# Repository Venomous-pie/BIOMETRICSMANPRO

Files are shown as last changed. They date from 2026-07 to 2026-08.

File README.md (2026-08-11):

# Biometrics Time-In/Out System

An ESP32-based biometric attendance system. A fingerprint scanner node (WROOM) communicates wirelessly via ESP-NOW to a touchscreen display node (CrowPanel), which connects to the backend over WiFi.

---

## Table of Contents

1. [Architecture Overview](#1-architecture-overview)
2. [Hardware](#2-hardware)
3. [Power Requirements](#3-power-requirements)
4. [Wiring & Pinout](#4-wiring--pinout)
5. [Arduino IDE Setup](#5-arduino-ide-setup)
6. [Configuration Reference](#6-configuration-reference)
7. [First-Time Flash Order](#7-first-time-flash-order)
8. [Mock Server Usage](#8-mock-server-usage)
9. [Repository Layout](#9-repository-layout)
10. [Employee Sync Pipeline](#10-employee-sync-pipeline)
11. [ESP-NOW Message Types](#11-esp-now-message-types)
12. [Persistent Storage Map](#12-persistent-storage-map)
13. [Subsystem Deep-Dives](#13-subsystem-deep-dives)
14. [Development Workflow](#14-development-workflow)
15. [WROOM Serial Commands](#15-wroom-serial-commands)
16. [Testing Checklist](#16-testing-checklist)
17. [Backend API Endpoints](#17-backend-api-endpoints)
18. [Open Work & Known Issues](#18-open-work--known-issues)
19. [OTA Firmware Update Roadmap](#19-ota-firmware-update-roadmap)
20. [Design Notes](#20-design-notes)

---

## 1. Architecture Overview

Understanding the data flow before touching code will save you hours. The system has three tiers:

```
+-----------------------------------+        +-----------------------------------+
|      WROOM Node (ESP32-D0WD-V3)   |        |   CrowPanel Node (ESP32-S3 QFN56) |
|                                   |        |                                   |
|  AS608 Fingerprint Sensor         |        |  5" 800x480 Touchscreen (LVGL)    |
|  WiFi (NTP timekeeping — RTC TBD) |        |  Employee list and logs UI        |
|  WiFi (for NTP + backend calls)   |        |  WiFi (for backend sync)          |
|                                   |        |                                   |
|  Polls finger -> match -> sends   |<------>|  Receives match/enroll events     |
|  attendance event over ESP-NOW    | ESP-NOW|  Shows result screen              |
|                                   |        |                                   |
|  Handles: activation, NTP sync,   |        |  Handles: employee list sync,     |
|  fingerprint enroll/delete,       |        |  attendance log display,          |
|  factory reset                    |        |  WiFi setup UI, settings          |
+------------------+----------------+        +------------------+----------------+
                   | HTTPS (REST API)                            | HTTPS (REST API)
                   +---------------------------+-----------------+
                                               |
                                    +----------v-----------+
                                    |    ManPro Backend API |
                                    |  (demo.manpromanage- |
                                    |   ment.com or local  |
                                    |   mock server)        |
                                    +----------------------+
```

**How a time-in works, end to end:**

1. Employee places finger on the AS608 sensor on the WROOM.
2. WROOM matches the fingerprint to a stored template and resolves the employee ID.
3. WROOM sends a `{type: MATCH, emp_id: ..., ts: ...}` JSON packet to the CrowPanel via ESP-NOW.
4. CrowPanel displays the result screen (welcome / access denied) and logs the attendance locally.
5. CrowPanel uploads the log entry to the backend API over WiFi on the next sync cycle.

**ESP-NOW channel management:** Both nodes must use the same WiFi channel. The WROOM monitors the channel continuously; if the AP hops channels, the WROOM sends a `CHANNEL_HOP` notification so the CrowPanel resyncs without a reboot.

---

## 2. Hardware

| Node | Board | Chip | Role |
| --- | --- | --- | --- |
| CrowPanel | Elecrow CrowPanel 5" 800×480 | **ESP32-S3 (QFN56)** | Touchscreen UI, WiFi, backend comms |
| WROOM | ESP32-WROOM-32 dev module | **ESP32-D0WD-V3** | Fingerprint scanner, ESP-NOW bridge |

### CrowPanel SD Card Requirement (Deep Storage)

The system uses a **Smart Cache** architecture. The WROOM's AS608 fingerprint sensor acts as a fast L1 cache holding 127 active templates. The CrowPanel's SD Card acts as the primary "Deep Storage", holding an unlimited number of fingerprint templates for offline scale.

- **Requirement:** A MicroSD card (FAT32 formatted) must be inserted into the CrowPanel.
- **Directory Structure:** The firmware expects the directory `/templates/` at the root of the SD card.
- **File Format:** Templates are stored as raw 512-byte binary files (e.g., `/templates/<emp_id>_<finger_index>.bin`).

---

## 3. Power Requirements

### Supply Voltages

| Component | Voltage | Typical Current | Peak Current |
| --- | --- | --- | --- |
| ESP32-D0WD-V3 (WROOM-32 module)  | 3.3 V | ~80 mA idle | ~350 mA WiFi TX burst |
| CrowPanel ESP32-S3 (QFN56) board | 5 V (USB-C) or 3.3 V regulated | ~150 mA idle | ~500 mA with LCD backlight + WiFi |
| AS608 Fingerprint Sensor | 3.3 V | ~120 mA scanning | ~140 mA |
| DFPlayer Mini + Speaker | 5.0 V | ~20 mA idle | ~200 mA playing |

### Power Strategy

**During development:**

- Power the **CrowPanel** via its USB-C port from a PC or USB charger. The board has an onboard 3.3 V LDO — you do not need a separate regulator.
- Power the **WROOM dev board** via its USB-micro/USB-C port. Most WROOM dev boards also have a 3.3 V LDO.
- The **AS608** can be powered from the WROOM board's 3.3 V pin (labelled `3V3`). Its draw (~120–140 mA) is well within the AMS1117 LDO's 800 mA rating.

**In the final enclosure:**

- The WROOM + AS608 sub-assembly should be powered from a regulated **5 V 1 A** supply (e.g. USB wall adapter) feeding the WROOM dev board's USB connector, or via VIN if using a bare module with an external 3.3 V regulator.
- The CrowPanel should be powered independently via its USB-C connector from a **5 V 2 A** source. Its LCD backlight alone draws ~200 mA.
- **Do not share a USB port between the two boards** during development — each board needs its own Serial port for log monitoring and flashing.

### Wire Gauge

- For power rails: 26 AWG stranded is sufficient for the current levels involved.
- For UART signal lines: 28 AWG or 30 AWG.
- Keep wire runs under 30 cm to avoid voltage drop on the 3.3 V rail.

---

## 4. Wiring & Pinout

### WROOM — Complete Pin Map

| Pin | GPIO | Function | Notes |
| --- | --- | --- | --- |
| 3V3 | — | 3.3 V output | Powers AS608 |
| GND | — | Ground | Common ground for all peripherals |
| **UART1 RX** | **GPIO27** | AS608 TX -> | Connect to AS608 TXD pin |
| **UART1 TX** | **GPIO26** | AS608 RX <- | Connect to AS608 RXD pin |
| **GPIO34** | Input-only | AS608 T-OUT (touch detect) | Pulled HIGH by sensor when finger present |
| **GPIO21** | SDA | Reserved — RTC (future) | Not connected; reserved for DS3231 I2C |
| **GPIO22** | SCL | Reserved — RTC (future) | Not connected; reserved for DS3231 I2C |
| **UART2 RX** | **GPIO17** | DFPlayer TX <- | Audio RX (Use Logic Level Shifter!) |
| **UART2 TX** | **GPIO16** | DFPlayer RX -> | Audio TX (Use Logic Level Shifter!) |
| **GPIO13** | Output | Reserved — Buzzer (future) | Not connected; reserved for buzzer signal |
| **GPIO14** | Factory Reset | Active HIGH button | Uses internal pull-down; hold 5 s to wipe |

**Pins to avoid on ESP32-D0WD-V3 (WROOM-32):**

| GPIO | Reason |
| --- | --- |
| GPIO0 | Strapping pin — LOW at boot = download mode; do not pull low with external hardware |
| GPIO2 | Strapping pin — must be LOW during flash; avoid driving it during boot |
| GPIO12 | Strapping pin — sets flash voltage; keep floating or LOW |
| GPIO15 | Strapping pin — controls boot logging; keep floating for normal use |
| GPIO34–39 | Input-only — no internal pull-up/pull-down; cannot be driven as outputs |
| GPIO6–11  | Connected to internal SPI flash — do not use |

**Connector type:** JST-PH 2.0 mm 2-pin or standard 2.54 mm DuPont headers are both fine for a prototype enclosure.

---

### AS608 Fingerprint Sensor Wiring

| AS608 Pin | Connects to |
| --- | --- |
| VCC | WROOM 3V3 |
| GND | WROOM GND |
| TXD | WROOM GPIO27 (UART1 RX) |
| RXD | WROOM GPIO26 (UART1 TX) |
| T-OUT | WROOM GPIO34 |
| WAKEUP | Leave floating or tie to GND |

> The AS608 communicates at 57600 baud by default. The firmware initialises UART1 at this speed. Do not change it unless you also update `fingerprint_manager.cpp`.

---

### Audio (DFPlayer Mini) Wiring

> **Hardware Setup Notes:**
>
> - **Logic Level Converter:** The ESP32 is a 3.3V device, but the DFPlayer Mini runs best at 5V. The RX/TX lines are routed through a logic level converter to protect the ESP32 pins.
> - **Active Buzzer (Not Implemented — Future Work):** The active buzzer has not been integrated into the hardware. GPIO13 is physically reserved for it. When implemented, it requires an NPN transistor and a flyback diode to drive safely from the ESP32.

| Audio Pin | Connects to | Notes |
| --- | --- | --- |
| DFPlayer VCC | 5V Power Rail | Provide 5V for loud/clean audio |
| DFPlayer GND | Common GND | |
| DFPlayer RX | Logic Level Converter (HV) -> (LV) -> WROOM GPIO16 (TX) | Converts 3.3V TX to 5V |
| DFPlayer TX | Logic Level Converter (HV) -> (LV) -> WROOM GPIO17 (RX) | Converts 5V TX to 3.3V |
| DFPlayer SPK+ | Speaker Positive (+) | |
| DFPlayer SPK- | Speaker Negative (-) | |

_Place your audio files (e.g., `0001.mp3`, `0002.mp3`) inside a folder literally named `mp3` on the root of the SD card before inserting it into the DFPlayer._

---

### DS3231 RTC Module (Not Implemented — Future Work)

> **The DS3231 hardware RTC has not been integrated into the firmware.** GPIO21 (SDA) and GPIO22 (SCL) are physically reserved for it, and the `time_manager.cpp` file exists as a stub, but the RTC driver is not initialised at boot. The WROOM currently uses NTP as its sole time source and falls back to `millis()`-based offset if WiFi is unavailable.
>
> Integrating the DS3231 is tracked as a future implementation item. When implemented, refer to the wiring table below:

| DS3231 Pin | Planned Connection |
| --- | --- |
| VCC | WROOM 3V3 |
| GND | WROOM GND |
| SDA | WROOM GPIO21 |
| SCL | WROOM GPIO22 |
| SQW | Not connected |
| 32K | Not connected |

---

### CrowPanel — Key Pins

The CrowPanel 5" board is a self-contained unit. You do not need to wire any peripherals to it — the display, touch controller, and SD card are all onboard. The only external connection is USB-C for power and flashing.

| Function | Notes |
| --- | --- |
| USB-C | Power + Serial (CDC) for flashing and Serial Monitor |
| ESP-NOW radio | Uses onboard antenna; no external connection needed  |
| WiFi | Uses onboard antenna |

**Pins to avoid on ESP32-S3 (QFN56) (if you ever need to expand):**

| GPIO | Reason |
| --- | --- |
| GPIO0 | Strapping pin — boot mode selection |
| GPIO3 | Strapping pin |
| GPIO19, GPIO20 | USB D+/D− — used by CDC USB port |
| GPIO26–32 | Connected to OPI PSRAM — do not use |
| GPIO33–37 | Connected to onboard flash — do not use |

---

## 5. Arduino IDE Setup

**Version:** Arduino IDE 2.3.10

> Since the IDE's Tools menu settings are **per-board-selection** and do not persist per-sketch, always double-check the **Board** dropdown before flashing. Flashing the wrong sketch to the wrong board (or with the wrong partition scheme) will produce a silent bad build.

### Step 1 — Install Arduino IDE

Download the installer from https://www.arduino.cc/en/software — choose **Arduino IDE 2.3.10** (Windows Installer). Run with default options.

### Step 2 — Add the ESP32 Board Package

1. Open Arduino IDE -> **File -> Preferences**.
2. In **Additional boards manager URLs**, paste:
   ```
   https://raw.githubusercontent.com/espressif/arduino-esp32/gh-pages/package_esp32_index.json
   ```
3. Click **OK**.
4. Go to **Tools -> Board -> Boards Manager**, search for `esp32`, and install **esp32 by Espressif Systems**.
   - **Required version: 3.2.0** (or the latest 3.x release). Version 2.x is not compatible with the ESP32-S3 PSRAM driver used by the CrowPanel.

### Step 3 — Install Libraries

Open **Tools -> Manage Libraries** and install each of the following by searching the Library Manager:

**For CrowPanel:**

| Search Term | Library to Install | Pin Version To |
| --- | --- | --- |
| Adafruit BusIO | Adafruit BusIO | 1.17.4 |
| DFRobot DFPlayer | DFRobotDFPlayerMini | 1.0.6 |
| LovyanGFX | LovyanGFX (by lovyan03) | 1.2.25 |
| lvgl | lvgl (by kisvegabor) | **8.3.11** |

> ⚠️ **LVGL is pinned to 8.3.11.** Version 9.x contains breaking API changes affecting `lv_obj_t` styling and display driver registration. Do **not** allow Library Manager to auto-update this library.

**For WROOM:**

| Search Term | Library to Install | Version |
| --- | --- | --- |
| Adafruit BusIO | Adafruit BusIO | 1.17.4  |
| Adafruit Fingerprint | Adafruit Fingerprint Sensor Library | 2.1.4 |
| ArduinoJson | ArduinoJson (by Benoit Blanchon) | 7.4.3 |

The following are used directly but bundled with the ESP32 board package — no separate install needed: `WiFi`, `WiFiUdp`, `HTTPClient`, `esp_now`, `esp_system`, `esp_wifi`, `Preferences`, `Wire`, `time.h`.

---

### CrowPanel — ESP32-S3 (QFN56) Board Settings

| Setting | Value |
| --- | --- |
| Board | ESP32S3 Dev Module |
| USB CDC On Boot | Enabled |
| CPU Frequency | 240MHz (WiFi) |
| Core Debug Level | None |
| USB DFU On Boot | Disabled |
| Erase All Flash Before Sketch Upload | Disabled |
| Events Run On | Core 1 |
| Flash Mode | QIO 80MHz |
| Flash Size | 4MB (32Mb) |
| JTAG Adapter | Disabled |
| Arduino Runs On | Core 1 |
| USB Firmware MSC On Boot | Disabled |
| **Partition Scheme** | **Huge APP (3MB No OTA/1MB SPIFFS)** |
| **PSRAM** | **OPI PSRAM** |
| Upload Mode | UART0 / Hardware CDC |
| Upload Speed | 921600 |
| USB Mode | Hardware CDC and JTAG |
| Zigbee Mode | Disabled |

### WROOM Controller — ESP32-D0WD-V3 Board Settings

| Setting | Value |
| --- | --- |
| Board | ESP32 Dev Module |
| CPU Frequency | 240MHz (WiFi/BT) |
| Core Debug Level | None |
| **Erase All Flash Before Sketch Upload** | **Enabled** |
| Events Run On | Core 1 |
| Flash Frequency | 80MHz |
| Flash Mode | QIO |
| Flash Size | 4MB (32Mb) |
| JTAG Adapter | Disabled |
| Arduino Runs On | Core 1 |
| **Partition Scheme** | **Default 4MB with spiffs (1.2MB APP/1.5MB SPIFFS)** |
| **PSRAM** | **Disabled** |
| Upload Speed | 921600 |
| Zigbee Mode | Disabled |

> **WROOM:** "Erase All Flash Before Sketch Upload" must be Enabled. The Preferences (NVS) partition layout changed during development and stale data causes silent failures on boot.

---

## 6. Configuration Reference

All runtime-tunable values are defined in the files below. Edit these before flashing to match your environment.

### `wroom_firmware/src/config.h`

| Constant | Default | What it controls |
| --- | --- | --- |
| `DEVICE_ID` | `F001-2608-6AEC-ON92` | Unique device identifier sent to backend during activation. Must match `DEVICE_ID_HARDCODED` in `data_manager.h`. |
| `API_BASE_URL` | `https://demo.manpromanagement.com` | Backend base URL. Change to `http://192.168.x.x:8000` for local mock server. |
| `ESPNOW_CHANNEL` | `1` | Fixed WiFi channel for ESP-NOW. Your router must be locked to this channel. |
| `ESPNOW_PAYLOAD_MAX` | `251` | Maximum ESP-NOW packet size in bytes. Do not increase beyond 250. |
| `PIN_FP_RX` | `27` | UART1 RX — receives data from AS608 TXD pin. |
| `PIN_FP_TX` | `26` | UART1 TX — sends data to AS608 RXD pin. |
| `PIN_FP_TOUCH` | `34` | Input from AS608 T-OUT (finger present detect). |
| `PIN_FACTORY_RESET`  | `14` | Active-HIGH button. Hold for 5 s to factory reset. |
| `MAX_SLOTS` | `127` | AS608 fingerprint template slot limit. Do not increase. |

### `wroom_firmware/src/comms.cpp`

| Variable | Default | What it controls |
| --- | --- | --- |
| `CROWPANEL_MAC[6]` | `{0x30, 0xED, ...}` | Station MAC address of the CrowPanel. **You must update this** before flashing the WROOM (see Section 7). |

### `crowpanel_firmware/src/core/comm_manager.h`

| Variable | Default | What it controls |
| --- | --- | --- |
| `WROOM_MAC[6]` | `{0x30, 0x76, ...}` | Station MAC address of the WROOM. **You must update this** before flashing the CrowPanel. |
| `API_BASE_URL` | `https://demo.manpromanagement.com` | Backend base URL for CrowPanel attendance uploads. |

### `crowpanel_firmware/src/core/data_manager.h`

| Constant | Default | What it controls |
| --- | --- | --- |
| `DEVICE_ID_HARDCODED` | `F001-2608-6AEC-ON92` | Must match `DEVICE_ID` in WROOM `config.h`. Both boards send this to the backend to prove they belong to the same registered unit. |

> ⚠️ **The device ID versioning scheme is not yet defined.** `data_manager.h` has a TODO: _"Make this dynamic, get the versioning pattern from senior dev."_ For now, assign IDs manually and keep them in sync across both files.

### Time / NTP (`wroom_firmware/src/time_manager.cpp`)

> **Note:** The DS3231 RTC is not yet implemented. `time_manager.cpp` currently only handles NTP sync and `millis()`-based fallback.

| Value | Default | What it controls |
| --- | --- | --- |
| UTC offset | `8 * 3600` (UTC+8 / PST) | Change the multiplier for your timezone, e.g. `7 * 3600` for ICT (UTC+7). |
| Primary NTP server  | `pool.ntp.org` | Standard global NTP pool. |
| Fallback NTP server | `time.google.com` | Used if the primary is unreachable. |

### WiFi Credentials

WiFi credentials are **not** hardcoded — they are entered at runtime via the CrowPanel **Settings -> WiFi** screen and stored in LittleFS. There is no file to edit for WiFi; just use the on-device UI.

---

## 7. First-Time Flash Order

> Always flash the CrowPanel first. The WROOM needs the CrowPanel's MAC address baked in before it can pair.

### Step 1 — Flash CrowPanel and get its MAC

1. Open `crowpanel_firmware/crowpanel_firmware.ino` in Arduino IDE.
2. Select **Tools -> Board -> ESP32S3 Dev Module** and apply all settings from the CrowPanel board settings table.
3. Connect the CrowPanel via USB-C. Select its port under **Tools -> Port**.
4. Click **Upload** (arrow button). Wait for "Done uploading."
5. Open **Tools -> Serial Monitor**. Set baud rate to **115200** and line ending to **Newline**.
6. Press the reset button on the CrowPanel (or power-cycle it).
7. Wait for the boot log. Within ~3 seconds you should see:
   ```
   [BOOT] CP MAC: 30:ED:A0:31:70:EC
   [DISPLAY] Init OK
   [LVGL] Ready
   ```
8. **Copy the full MAC address** from the `[BOOT] CP MAC:` line.

> **If nothing appears in Serial Monitor:** Make sure `USB CDC On Boot` is set to **Enabled** in board settings, and that you have selected the correct COM port. On Windows, open Device Manager and look for "USB Serial Device (COMx)" under Ports.

---

### Step 2 — Update WROOM firmware with CrowPanel MAC

1. Open `wroom_firmware/src/comms.cpp`.
2. Find the line:
   ```cpp
   uint8_t CROWPANEL_MAC[6] = {0x30, 0xED, 0xA0, 0x31, 0x70, 0xEC};
   ```
3. Replace the 6 hex bytes with the MAC you copied in Step 1. For example, if the MAC was `A4:CF:12:AB:CD:EF`:
   ```cpp
   uint8_t CROWPANEL_MAC[6] = {0xA4, 0xCF, 0x12, 0xAB, 0xCD, 0xEF};
   ```
4. Also update `WROOM_MAC[6]` in `crowpanel_firmware/src/core/comm_manager.h` with the WROOM's own MAC (shown as `[BOOT] WROOM MAC:` when you flash the WROOM in Step 3).
5. Save both files.

---

### Step 3 — Flash WROOM

1. Open `wroom_firmware/wroom_firmware.ino` in Arduino IDE.
2. Select **Tools -> Board -> ESP32 Dev Module** and apply all settings from the WROOM board settings table.
3. Connect the WROOM via USB. Select its port under **Tools -> Port**.
4. Click **Upload**. Because `Erase All Flash Before Sketch Upload` is enabled, this takes ~30 seconds on the first flash.
5. Open **Tools -> Serial Monitor** at **115200 baud**.
6. Press reset on the WROOM. Expected boot sequence:
   ```
   === Biometrics WROOM Controller ===
   [BOOT] Reset reason: 1
   [WIFI] Attempting to connect to saved network...
   [AS608] Found! Templates stored: 3
   [ESPNOW] Peer registered: 30:ed:a0:31:70:ec
   Ready. Serial commands:
     ENROLL:<emp_id>:<finger_index>  e.g. ENROLL:1:0
     DELETE:<emp_id>:<finger_index>  e.g. DELETE:1:0
     RESET
   ```
7. Note the `[BOOT] WROOM MAC:` line. Go back and update `WROOM_MAC[6]` in `comm_manager.h` if not already done, then re-flash the CrowPanel.
8. On the CrowPanel, you should briefly see a "WROOM online" toast confirming the link is live.

---

### Step 4 — WiFi Setup and Activation

1. On the CrowPanel, navigate to **Settings -> WiFi**.
2. Scan for networks, select your AP, and enter the password using the on-screen keyboard.
3. Once connected, navigate to **Settings -> Activation** and enter your ManPro registration code.
4. The WROOM calls the backend API to validate, and both boards mark themselves as activated.

---

### Pairing Troubleshooting

| Symptom | Likely Cause | Fix |
| --- | --- | --- |
| `[ESPNOW] Send fail` repeated in WROOM Serial  | Wrong MAC address in `comms.cpp` | Re-read CrowPanel MAC and update `comms.cpp`. |
| No "WROOM online" toast on CrowPanel | Channel mismatch | Lock router to a fixed channel and match `ESPNOW_CHANNEL` in `config.h`. |
| `[AS608] NOT FOUND` in WROOM Serial | Wiring error or wrong baud | Check GPIO26/27 connections. Swap RX/TX if reversed. |

| CrowPanel shows blank/white screen after flash | Wrong partition or PSRAM setting | Re-check: Partition = Huge APP, PSRAM = OPI PSRAM.                       |

---

## 8. Mock Server Usage

Use the mock server during development when you do not have access to the live ManPro backend.

### Prerequisites

- Python 3.9 or later
- `pip install flask`

### Starting the Mock Server

```bash
cd mock_server
pip install -r requirements.txt
python mock_server.py
```

The server starts on `http://0.0.0.0:8000` by default and prints available endpoints on startup.

### Pointing the Firmware at the Mock Server

1. Find your development machine's LAN IP address (e.g. `192.168.1.50`).
2. Open `wroom_firmware/src/config.h` and change:
   ```cpp
   #define API_BASE_URL "http://192.168.1.50:8000"
   ```
3. Also change `API_BASE_URL` in `crowpanel_firmware/src/core/comm_manager.h` to the same value.
4. Ensure both devices and your development machine are on the same WiFi network, then flash.

> The mock server returns canned responses for all endpoints. Check its console output to see every request the firmware makes — this is useful for debugging sync issues.

> `crowpanel_firmware/tools/admin_mock.py` is a separate, lightweight admin mock. It is **incomplete** and does not cover all endpoints — use the main mock server above instead.

---

## 9. Repository Layout

```
BIOMETRICSMANPRO/
├── README.md                             # This file
├── docs/
│   └── admin_manual.md                  # End-user / admin UI guide
├── crowpanel_firmware/
│   ├── crowpanel_firmware.ino            # Entry point: setup() + loop(), LVGL init
│   ├── tools/
│   │   ├── convert_img.py               # Converts PNG -> LVGL C array
│   │   ├── run_conv.py                  # Batch runner for convert_img.py
│   │   └── admin_mock.py               # Partial admin API mock (incomplete)
│   └── src/
│       ├── core/
│       │   ├── display_driver.h         # LovyanGFX LGFX config (pins, resolution, touch)
│       │   ├── data_manager.h/.cpp      # All persistent state: employees, logs, settings
│       │   ├── comm_manager.h/.cpp      # ESP-NOW init, RX ring buffer, JSON dispatch
│       │   ├── sync_receiver.h/.cpp     # Binary protocol handler for employee sync
│       │   ├── sync_protocol.h          # Shared packet structs (MUST match WROOM copy)
│       │   └── certs.h                  # GTS Root R4 CA cert for HTTPS
│       ├── ui/
│       │   ├── ui_manager.h/.cpp        # Screen router, showXxx() navigation
│       │   ├── ui_idle.h/.cpp           # Standby screen (clock, finger prompt)
│       │   ├── ui_result.h/.cpp         # Post-scan feedback (green=OK, red=fail)
│       │   ├── ui_pin.h/.cpp            # Admin PIN entry + lockout logic
│       │   ├── ui_main_menu.h/.cpp      # Admin hub (Enroll / Logs / Settings)
│       │   ├── ui_enroll.h/.cpp         # Fingerprint enrolment wizard
│       │   ├── ui_logs.h/.cpp           # Attendance log viewer
│       │   ├── ui_settings.h/.cpp       # Settings hub
│       │   ├── ui_settings_clock.h/.cpp # Manual time/date picker
│       │   ├── ui_settings_danger.h/.cpp# Factory reset / nuke confirmations
│       │   ├── ui_settings_display.h/.cpp # Brightness + timeout sliders
│       │   ├── ui_settings_server.h/.cpp# API base URL override
│       │   ├── ui_wifi_setup.h/.cpp     # WiFi scan + connect UI
│       │   ├── ui_sync_status.h/.cpp    # Sync log viewer
│       │   └── ui_activation.h/.cpp     # Device registration screen
│       ├── splash/
│       │   └── manpro_splash.h          # Boot animation (calls UIManager::loadInitialScreen)
│       └── assets/                      # Compiled LVGL C arrays (icons, fonts)
├── wroom_firmware/
│   ├── wroom_firmware.ino               # Entry point: setup() + loop()
│   └── src/
│       ├── config.h                     # Pin defs, DEVICE_ID, API_BASE_URL, ESP-NOW constants
│       ├── certs.h                      # GTS Root R4 CA cert for HTTPS
│       ├── employee_db.h/.cpp           # Slot->emp_id mapping (stored in NVS)
│       ├── comms.h/.cpp                 # ESP-NOW send/recv, ring buffer, CROWPANEL_MAC
│       ├── wifi_manager.h/.cpp          # WiFi connect, scan, auto-reconnect
│       ├── time_manager.h/.cpp          # NTP timekeeping + millis fallback (DS3231 RTC: future work)
│       ├── fingerprint_manager.h/.cpp   # AS608 sensor: match, enroll, delete
│       ├── activation.h/.cpp            # POST /api/devices/activate -> store token
│       ├── sync_manager.h/.cpp          # Employee sync state machine
│       ├── sync_protocol.h             # Shared packet structs (MUST match CrowPanel copy)
│       └── command_handler.h/.cpp       # Dispatches Serial + ESP-NOW JSON commands
├── assets/
│   ├── logo/                            # Source ManPro logo PNGs
│   ├── icons/                           # Source icon PNGs (converted by tools/)
│   └── boot_anim/                       # Boot animation frames
└── ui_reference/                        # Color palette & design reference screenshots
```

---

## 10. Employee Sync Pipeline

The employee list lives on the ManPro backend. This is the most complex subsystem.

```
ManPro Backend API
     |
     |  GET /api/devices/employees  (HTTPS, Bearer token)
     v
WROOM: SyncManager::fetchEmployeesFromApi()
     |  Parses JSON -> EmployeeSync[] buffer
     |  Handles 5 wrapper key styles: "employees", "data", "result", "payload", bare array
     |
     |  Binary framed over ESP-NOW (sync_protocol.h)
     |  PING -> PONG -> SYNC_START -> SYNC_DATA[n] -> SYNC_END -> SYNC_RESULT
     v
CrowPanel: SyncReceiver
     |  Assembles chunks, verifies CRC32
     |  DataManager::applySyncBuffer() -> empDB[]
     |  Persists to LittleFS (/employees.json)
     |  DataManager::loadFpState() re-applies enrollment bitmask after overwrite
     v
     SYNC_RESULT (OK or NACK with list of missing chunk indices)
     v
WROOM: SyncManager::handleIncomingPacket()
     |  OK  -> SYNC_STATE_IDLE
     |  NACK -> resend missing chunks -> re-send SYNC_END
```

### SyncManager State Machine (WROOM)

States in order:
`IDLE -> FETCH_WIFI -> SET_ESPNOW_CHANNEL -> SEND_PING -> SEND_SYNC_START -> SEND_CHUNKS -> SEND_SYNC_END -> AWAIT_SYNC_RESULT`

- Failure at any state triggers `failToFastRetry()` — enters `FAST_RETRY_MODE` (retries every 5 minutes).
- Sync triggers: (a) manually via `SYNC_EMP` ESP-NOW command from CrowPanel, or (b) automatically at the top of every hour when NTP time is valid.
- **BUG-10 fix** (applied): `s_syncEndResendCount` is a separate counter from `s_retryCount` because `setState()` resets `s_retryCount` — a unified counter made the 3-retry limit on SYNC_END resends unreachable.
- **EDGE-07 fix** (applied): `sync_id` falls back to a monotonic counter if `time(NULL)` returns a pre-NTP epoch value (< 1,000,000,000), preventing stale-packet acceptance from a prior session.

### sync_protocol.h — The Contract

Both firmwares include a **copy** of `sync_protocol.h`. They must be **byte-for-byte identical**. If you change a struct or add a packet type, update both copies. Struct sizes are enforced at compile time via `static_assert`.

| Packet | Direction | Purpose |
| --- | --- | --- |
| `SYNC_PING` / `SYNC_PONG` | WROOM <-> CrowPanel | Confirm ESP-NOW link before starting |
| `SYNC_START` | WROOM -> CrowPanel  | Declares `sync_id`, total chunks, total bytes |
| `SYNC_DATA` | WROOM -> CrowPanel  | One chunk of raw `EmployeeSync[]` bytes |
| `SYNC_CHUNK_ACK` | CrowPanel -> WROOM  | Confirms receipt of a specific chunk index |
| `SYNC_END` | WROOM -> CrowPanel  | Signals completion, carries CRC32 |
| `SYNC_RESULT` | CrowPanel -> WROOM  | OK or NACK with list of missing chunk indices |

`MAX_SYNC_EMPLOYEES = 127` — matches the AS608 slot limit. Do not increase without also expanding the fingerprint slot pool.  
`MAX_CHUNK_SIZE = 200` bytes — the largest transmitted packet must stay ≤ 250 bytes (ESP-NOW hard limit).

---

## 11. ESP-NOW Message Types

Most inter-node communication uses **JSON strings** sent over ESP-NOW. Only the employee sync uses binary packets (see Section 10). The message type field is `"type"`. The CrowPanel's `CommManager::dispatchJson()` routes all incoming JSON messages.

| `type` | Direction | Description |
| --- | --- | --- |
| `MATCH` | WROOM -> CrowPanel | Fingerprint matched: `{emp_id, name, ts, confidence, slot, action_type}` |
| `ENROLL_RESULT` | WROOM -> CrowPanel | Enrolment result: `{success, emp_id, finger_index, slot, msg}` |
| `EMP_SYNC_START` | CrowPanel -> WROOM | Trigger employee sync (WROOM starts SyncManager) |
| `EMP_SYNC_FAIL` | WROOM -> CrowPanel | Sync failed — stop UI loading spinner |
| `ACTIVATION_STATUS` | WROOM -> CrowPanel | Activation API result: `{activated, token}` |
| `NTP_STATUS` | WROOM -> CrowPanel | Timestamp string to set CrowPanel RTC: `{time_str}` |
| `WIFI_STATUS` | WROOM -> CrowPanel | WiFi state update: `{connected, ssid, ip}` |
| `CHANNEL_HOP` | WROOM -> CrowPanel | AP changed channel; CrowPanel must re-init ESP-NOW |
| `WROOM_ONLINE` | WROOM -> CrowPanel | Heartbeat on boot — triggers "WROOM online" toast |
| `GHOST_LOGIN` | WROOM -> CrowPanel | Dev backdoor — bypasses scanner, opens Main Menu |
| `NUKE_USERS` | WROOM -> CrowPanel | Dev backdoor — erases all fingerprint slots except slot 1 |
| `DEBUG_COMMS` | WROOM -> CrowPanel | Dev backdoor — toggles ESP-NOW ping/pong debug output |

---

## 12. Persistent Storage Map

### WROOM — NVS (Preferences namespace `"biometrics"`)

| Key | Type | Content |
| --- | --- | --- |
| `activated` | bool | Whether device has been activated |
| `device_token` | String | Bearer token from backend |
| `wifi_ssid` | String | Saved WiFi network |
| `wifi_pass` | String | Saved WiFi password |
| `emp_count` | int | Number of entries in slot map |
| `emp_X_id` | String | Employee ID for slot X |
| `emp_X_fi` | int | Finger index for slot X |

The AS608 sensor is the physical store for fingerprint templates. NVS only stores the slot→emp_id lookup table, managed by `employee_db.h/.cpp`.

### CrowPanel — LittleFS

| File | Format | Content |
| --- | --- | --- |
| `/employees.json`  | JSON array | Employee list (name, dept, job_title, branch, fp_enrolled, enrolled_fingers) |
| `/config.json` | JSON object | Device settings (brightness, timeout, volume, adminPin, deviceName, activated, token) |
| `/wifi.json` | JSON array (up to 5) | Saved WiFi credentials |
| `/attendance.json` | JSON array (up to 200) | Local attendance log (name, time_str, action_type, synced, confidence, slot) |
| `/fp_state.json` | JSON object | Enrollment bitmask per emp_id — persisted separately so it survives sync overwrites |
| `/sync_log.jsonl`  | JSON Lines | Last 5 sync event messages with timestamps |

### CrowPanel — SD Card (`/templates/`)

Raw 512-byte binary fingerprint templates stored as `/templates/<emp_id>_<finger_index>.bin`. This is the **Deep Storage** layer — the WROOM's AS608 is L1 cache (127 slots); the SD card is the primary store for larger employee sets. Templates are loaded from SD and pushed to WROOM on demand during enrolment or sync.

---

## 13. Subsystem Deep-Dives

### CrowPanel Boot Sequence

```
setup():
  DataManager::begin()         -> mounts LittleFS, loads all JSON files
  CommManager::begin()         -> inits ESP-NOW, registers onEspNowRecv callback
  lcd.init()                   -> LovyanGFX + GPIO2 backlight reset
  lv_init()                    -> allocates PSRAM render buffers (2x 800x240 px)
  manpro_show_splash(callback) -> plays boot animation, then calls UIManager::loadInitialScreen
  UIManager::begin()           -> builds all LVGL screen objects

loop():
  lv_tick_inc() + lv_task_handler()   -> LVGL rendering tick
  CommManager::process()              -> drains ring buffer, dispatches JSON messages
  Screen timeout check                -> dims backlight after inactivity
```

`UIManager::loadInitialScreen` decides which screen shows after the splash: Activation screen (not activated) → WiFi setup (no saved credentials) → Idle screen (normal operation).

### WROOM Boot Sequence

```
setup():
  WiFiManager::begin()         -> attempts to connect to saved network
  FingerprintManager::init()   -> opens AS608 on UART1, counts stored templates
  TimeManager::init()          -> syncs NTP if WiFi available (DS3231 RTC: not yet implemented)
  Comms::begin()               -> inits ESP-NOW, registers CROWPANEL_MAC as peer
  SyncManager::init()          -> sets state to IDLE
  AudioManager::init()         -> inits DFPlayer Mini on UART2

loop():
  CommandHandler::poll()       -> polls AS608 T-OUT pin, reads Serial commands
  SyncManager::loop()          -> drives sync state machine, hourly auto-trigger
```

### Admin PIN System

- Default PIN: `0000` (set in `DataManager` default config).
- PIN is stored in `/config.json` (plaintext — no hashing currently).
- Lockout: 5 consecutive wrong attempts → 60-second lockout. Tracked in `DataManager::_failedAttempts` / `_lockoutStartTime`, persisted in config across reboots.
- PIN change: **Settings → Danger Zone** (requires current PIN first).
- Admin fingerprint: A special enrolment with `emp_id = "ADMIN"` stored on the SD card. Placing the admin finger on the idle screen opens Main Menu directly without PIN entry.

### Smart Cache Architecture

```
AS608 (WROOM) — L1 cache, 127 slots
  ^ push on enrolment
  v evict: NOT YET IMPLEMENTED (see Section 18)

SD Card (CrowPanel) — Deep storage, unlimited
  /templates/<emp_id>_<finger_index>.bin

ManPro Backend — Source of truth for employee records
```

**Enrolment flow:**

1. CrowPanel UI sends `ENROLL:<emp_id>:<finger_index>` command to WROOM.
2. WROOM captures template on AS608 (gets a physical slot number).
3. WROOM sends the 512-byte template back to CrowPanel in `ENROLL_RESULT`.
4. CrowPanel saves template to SD card.
5. `employee_db` on WROOM stores the slot→emp_id mapping in NVS.

### Time Source Priority

The WROOM currently uses a two-tier clock source:

1. **NTP** (requires WiFi) — synced on boot whenever WiFi is available.
2. **`millis()`-based offset** (last resort — drifts; no persistent timekeeping without WiFi).

> **DS3231 hardware RTC is a planned future implementation.** When added it will serve as a battery-backed middle tier, preserving time across power cycles even without WiFi. GPIO21/22 are already reserved. See the [DS3231 wiring section](#ds3231-rtc-module-not-implemented--future-work) for planned connection details.

---

## 14. Development Workflow

### Sensor-less Testing (WROOM)

Uncomment `#define MOCK_SENSOR 1` in `wroom_firmware/src/config.h`. This simulates fingerprint scans without physical hardware. The `GHOST_LOGIN` Serial command also bypasses the scanner and sends a fake match event to the CrowPanel.

### Image Asset Pipeline

Icons live as source PNGs in `assets/icons/`. To update or add icons:

```bash
cd crowpanel_firmware/tools
python run_conv.py    # batch converts assets/icons/ -> src/assets/*.c
```

The resulting `.c` files are `#include`d into the firmware and declared with `LV_IMG_DECLARE()`.

### Key Files by Area

| Area | Primary Files |
| --- | --- |
| All persistence (CrowPanel) | `data_manager.h` / `data_manager.cpp` |
| ESP-NOW receive + JSON routing (CrowPanel) | `comm_manager.h` / `comm_manager.cpp` |
| Employee sync — sender (WROOM) | `sync_manager.h` / `sync_manager.cpp` |
| Employee sync — receiver (CrowPanel) | `sync_receiver.h` / `sync_receiver.cpp` |
| Binary packet definitions (both nodes) | `sync_protocol.h` — **keep both copies identical**  |
| Fingerprint hardware (WROOM) | `fingerprint_manager.h` / `fingerprint_manager.cpp` |
| All UI screens (CrowPanel) | `src/ui/ui_*.h` / `src/ui/ui_*.cpp` |
| Screen navigation / routing | `ui_manager.h` / `ui_manager.cpp` |
| Hardware config + pins | `wroom_firmware/src/config.h` |

---

## 15. WROOM Serial Commands

Connect at **115200 baud**.

| Command | Description |
| --- | --- |
| `ENROLL:<emp_id>:<finger_index>` | Enroll a finger (e.g. `ENROLL:1:0` = employee 1, first finger) |
| `DELETE:<emp_id>:<finger_index>` | Erase a stored template (e.g. `DELETE:1:0`) |
| `RESET` | Reboot the WROOM |
| `TEST_HW` | Hardware test (Plays Track 1) |
| `GHOST_LOGIN` | Dev backdoor — bypasses scanner, jumps to Main Menu on CrowPanel |
| `NUKE_USERS` | Dev backdoor — erases all stored fingerprints except slot 1 |
| `DEBUG_COMMS` | Dev backdoor — toggles ESP-NOW ping/pong debug output |

---

## 16. Testing Checklist

No automated tests exist. Verify the following manually before any release:

- [ ] Cold boot (power off) → splash animation plays → idle screen loads with correct time
- [ ] Fingerprint time-in → result screen shows correct name and "Time In" → log entry appears in Logs screen
- [ ] Fingerprint time-out → "Time Out" result screen
- [ ] Unrecognized finger → "Not Recognized" result → no log entry written
- [ ] Employee sync triggered from Settings → `[SYNC]` log messages in WROOM Serial → CrowPanel Sync Status screen shows updated employee list
- [ ] Admin PIN: correct PIN opens Main Menu; wrong PIN × 5 triggers 60s lockout
- [ ] WiFi disconnected during sync → WROOM enters FAST_RETRY_MODE → retries after 5 minutes
- [ ] Factory reset on CrowPanel → all data wiped → returns to WiFi setup screen
- [ ] Factory reset on WROOM (hold GPIO14 for 5 s) → fingerprints wiped → NVS cleared
- [ ] Channel hop: change router channel → both nodes re-negotiate within ~10 s

---

## 17. Backend API Endpoints

The firmware calls these endpoints. Consult the ManPro backend team for authentication details and any schema changes.

| Method | Endpoint | Caller | Purpose |
| --- | --- | --- | --- |
| `POST` | `/api/devices/activate`  | WROOM `activation.cpp` | Register device, receive bearer token |
| `GET`  | `/api/devices/employees` | WROOM `sync_manager.cpp` | Fetch employee list for binary sync to CrowPanel |
| `POST` | `/api/attendance` | CrowPanel `data_manager.cpp` | Upload attendance log entries |

Authentication: `Authorization: Bearer <device_token>` header. Token is obtained during activation and stored in WROOM NVS and CrowPanel `/config.json`.

> `sync_manager.cpp` tries five different JSON wrapper keys (`employees`, `data`, `result`, `payload`, bare array) to handle backend response format variations. If the API schema changes, check `SyncManager::fetchEmployeesFromApi()` first.

---

## 18. Open Work & Known Issues

### Issue 1 — Device ID Versioning Scheme (Undefined)

`DEVICE_ID` in `config.h` and `DEVICE_ID_HARDCODED` in `data_manager.h` are hardcoded strings. A TODO comment in `data_manager.h` reads: _"Make this dynamic, get the versioning pattern from senior dev."_ Until the scheme is defined, IDs must be manually assigned and kept in sync across both files for each physical unit.

### Issue 2 — No Fingerprint Eviction Policy

The AS608 has a hard limit of 127 template slots. There is no LRU or frequency-based eviction policy. If more than 127 fingers are enrolled, enrolment will silently fail. This must be addressed before deploying at any site with more than 127 enrolled fingers.

### Issue 3 — sync_protocol.h Dual-Copy Maintenance Risk

Both `wroom_firmware/src/sync_protocol.h` and `crowpanel_firmware/src/core/sync_protocol.h` must stay byte-for-byte identical. There is no automated check enforcing this. **Any edit to either copy must be manually mirrored to the other.**

### Issue 4 — Admin PIN Stored in Plaintext

The admin PIN is stored as a plain string in `/config.json`. Consider hashing before production deployment.

### Issue 5 — Attendance Upload: No Retry Queue

`DataManager::uploadPendingLogs()` runs attendance POSTs on a FreeRTOS background task. If the task fails mid-batch, those logs remain as `synced=false` and are retried on the next upload cycle. This is acceptable for now but should be replaced with a proper retry queue before production.

### Issue 6 — WiFi Channel Lock Dependency

The router **must** be locked to a fixed channel (default: channel 1). If the router uses auto-channel, the WROOM sends a `CHANNEL_HOP` notification, but this path is not fully hardened. Always configure and test with a fixed channel.

### Issue 7 — OTA Firmware Updates Not Implemented

See Section 19 below.

---

## 19. OTA Firmware Update Roadmap

Both the WROOM and CrowPanel will autonomously check for new firmware over the internet, download it, and apply it — no USB cable needed after the one migration flash.

### How It Will Work

```
Your PC                  GitHub Releases                Devices (anywhere)
------                   ---------------                ------------------
Build .bin files  -push-> firmware_manifest.json        WROOM & CrowPanel
Tag a release           + wroom_v1.1.0.bin              check manifest on boot
                        + crowpanel_v1.1.0.bin  <------  and every 6 hours
                                                               |
                                                    If version newer: download
                                                    .bin over HTTPS -> flash
                                                    -> reboot into new firmware
```

### Open Questions Before Implementation

> ⚠️ **CrowPanel flash size** — The CrowPanel currently uses `Huge APP (3MB No OTA)`, occupying a 3 MB app slot. OTA requires two equal app slots. On a 4 MB chip, two 3 MB slots don't fit. Options:
>
> - **Option A (Recommended):** If the board ships with **16 MB flash** (many do — the `4MB` Arduino setting is a conservative default), use a custom 16 MB partition with two 6 MB app slots.
> - **Option B:** If truly 4 MB flash, reduce the CrowPanel firmware footprint to fit two ~1.9 MB OTA slots (may require stripping some compiled icon assets).
>
> **Action required:** In Arduino IDE with CrowPanel selected, go to `Sketch → Export Compiled Binary` and report the `.bin` file size. If under ~1.7 MB, 4 MB OTA works.

> ⚠️ **One final USB flash required.** Switching partition schemes wipes the existing partition table. Both boards need one last USB flash to migrate to the OTA-capable partition.

### Proposed Changes

**WROOM:**

- `config.h` — add `FIRMWARE_VERSION`, `OTA_MANIFEST_URL`, `OTA_CHECK_INTERVAL_MS`
- New `ota_manager.h/.cpp` — state machine: `IDLE → CHECK_VERSION → DOWNLOADING → DONE/FAILED`; uses `HTTPUpdate` + `GTS_ROOT_R4` cert; sends `OTA_STATUS` JSON to CrowPanel during download
- `command_handler.cpp` — handle `OTA_CHECK` command from CrowPanel
- Partition scheme: `Default 4MB with spiffs` → **Min SPIFFS (1.9MB APP with OTA/190KB SPIFFS)**

**CrowPanel:**

- New `src/core/ota_manager.h/.cpp` — checks manifest, calls `HTTPUpdate`, triggers WROOM OTA after self-update
- New `src/ui/ui_ota.h/.cpp` — LVGL overlay with "Update available" prompt + progress bar
- `ui_settings.cpp` — add "Firmware Update" entry to Settings menu
- `comm_manager.cpp` — handle incoming `OTA_STATUS` from WROOM
- Partition scheme: TBD (see Open Questions above)

**Shared:**

- `firmware_manifest.json` at repo root (served via GitHub raw URL)
- `sync_protocol.h` — add `OTA_STATUS` and `OTA_CHECK` message type constants

### Release Workflow (once implemented)

```
1. Edit firmware, bump FIRMWARE_VERSION in config.h
2. Arduino IDE -> Sketch -> Export Compiled Binary
3. Create a GitHub Release tagged "v1.x.x"
4. Upload wroom_v1.x.x.bin and crowpanel_v1.x.x.bin as release assets
5. Edit firmware_manifest.json with the new version + URLs
6. Commit and push
   -> Devices pick it up within 6 hours (or immediately on next boot)
```

---

## 20. Design Notes

**Partition schemes differ intentionally.** The CrowPanel uses _Huge APP (3MB)_ because LVGL + LovyanGFX + compiled icon assets consume significantly more flash than a typical sketch. OTA is not used on that board yet. The WROOM uses the standard _Default 4MB with spiffs_ scheme.

**PSRAM is enabled only on the CrowPanel.** LVGL's double display buffers (~160 KB each) are allocated from PSRAM at boot. The WROOM-32 module does not have PSRAM populated.

**ESP-NOW channel management.** Both boards must be on the same WiFi channel for ESP-NOW to work. The WROOM monitors the channel in real time and sends `CHANNEL_HOP` notifications to the CrowPanel whenever the AP channel changes, so they stay in sync without a reboot.

**Time source priority.** The WROOM currently uses two clock sources: NTP (requires WiFi, synced on boot) and a `millis()`-based offset as a last resort when offline. A DS3231 hardware RTC is planned as a battery-backed middle tier for future implementation — GPIO21/22 are already reserved for it.

**Employee data lives on the CrowPanel.** The CrowPanel stores the employee list in LittleFS and syncs it from the backend. The WROOM only stores fingerprint template slot-to-employee-ID mappings in its own flash via the `employee_db` module. A sync operation pushes the mapping table from CrowPanel to WROOM over ESP-NOW using a binary framed protocol (`sync_protocol.h`).

**Admin PIN is plaintext.** The PIN is stored as a plain string in `/config.json`. Hashing (e.g. SHA-256 via `mbedtls`) should be added before production deployment.

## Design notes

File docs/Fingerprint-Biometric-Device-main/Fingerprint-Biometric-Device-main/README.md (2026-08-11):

Manpro — Biometric Fingerprint Attendance/Access Device

KiCad hardware project for Manpro, a fingerprint-based attendance/access control device. The design is split into two boards — a project (logic) board and a power board — connected via JST connectors carrying GND / +5V / +3.3V.

Project Files
File	Purpose
JRDraws.kicad_pro	KiCad project file
JRDraws.kicad_sch	Main schematic (project board + power board)
JRDraws.kicad_pcb	PCB layout
JRDraws.kicad_prl	Local project settings
Dpad-button-controller.kicad_sch	Sub-schematic for the 5-button D-pad nav controller
fp-lib-table	Footprint library table
Hardware Overview

Main controller (project board)

ESP32 DevKit (38-pin) — main MCU
AS608 fingerprint sensor — RX → G26, TX → G27, T-OUT → G34
DFPlayer Mini (MH2024K) audio module — on G16/G17 via a 5V↔3.3V logic level converter
DS3231 RTC
CrowPanel Node (separate ESP32-S3) touchscreen UI
Buzzer/speaker — on G13
5 navigation push buttons (D-pad sub-board) + a dedicated hardware reset button tied to EN

Power board

USB-C receptacle (power only, 6-pin) input
MCP73871 (QFN-20) LiPo charge/power-path management IC
MT3608 boost converter module
3.7V 5000 mAh LiPo battery
Fuse + protection/flag circuitry

Passives/misc: several resistors and capacitors, 3 LEDs, PWR flag and GND/+5V/+3.3V power symbols throughout.

✔️AS608 TX/RX swap fixed
✔️Decided on a single AS608 sensor (not dual)
✔️ \5 nav buttons + hardware reset button wired correctly
✔️DFPlayer, AS608, and buzzer pins reassigned per updated reference doc

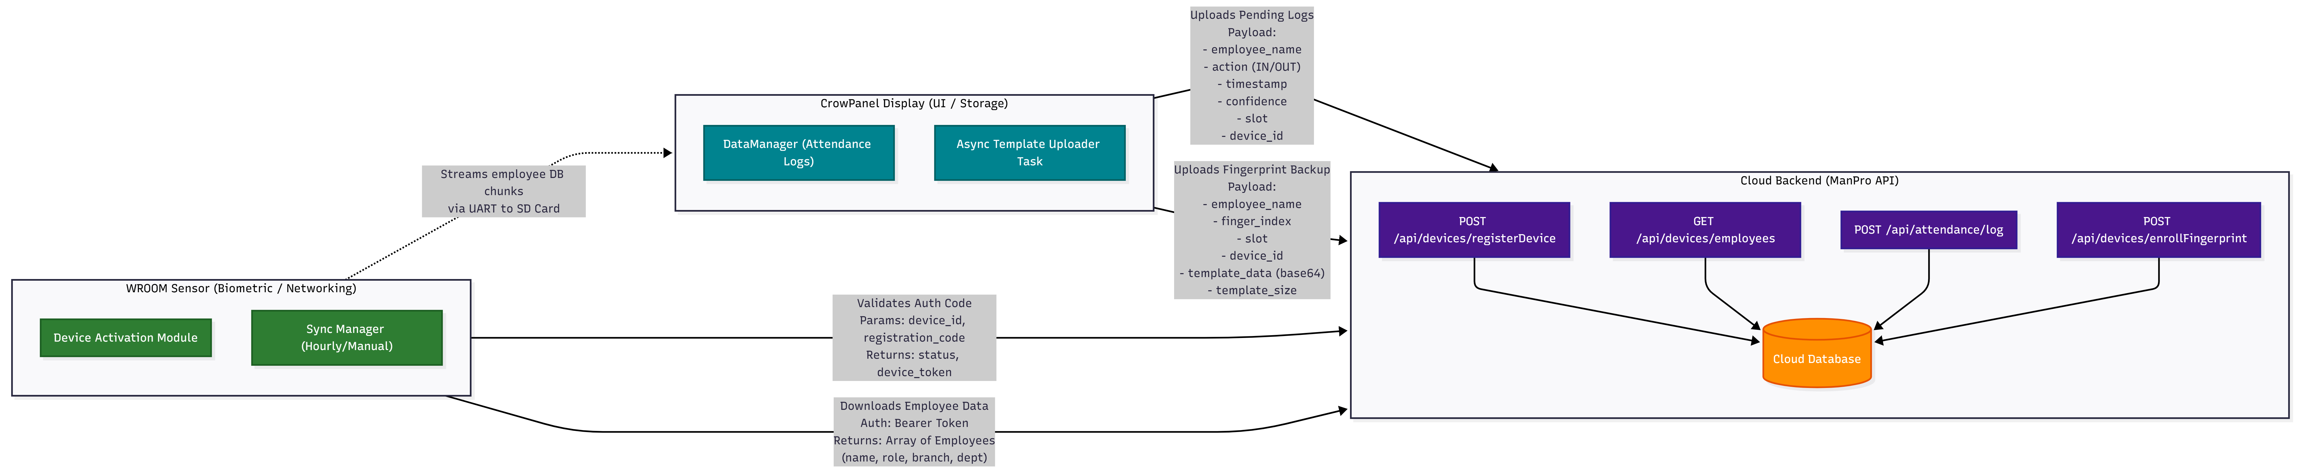
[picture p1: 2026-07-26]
docs/BACKEND_FLOWCHART.png

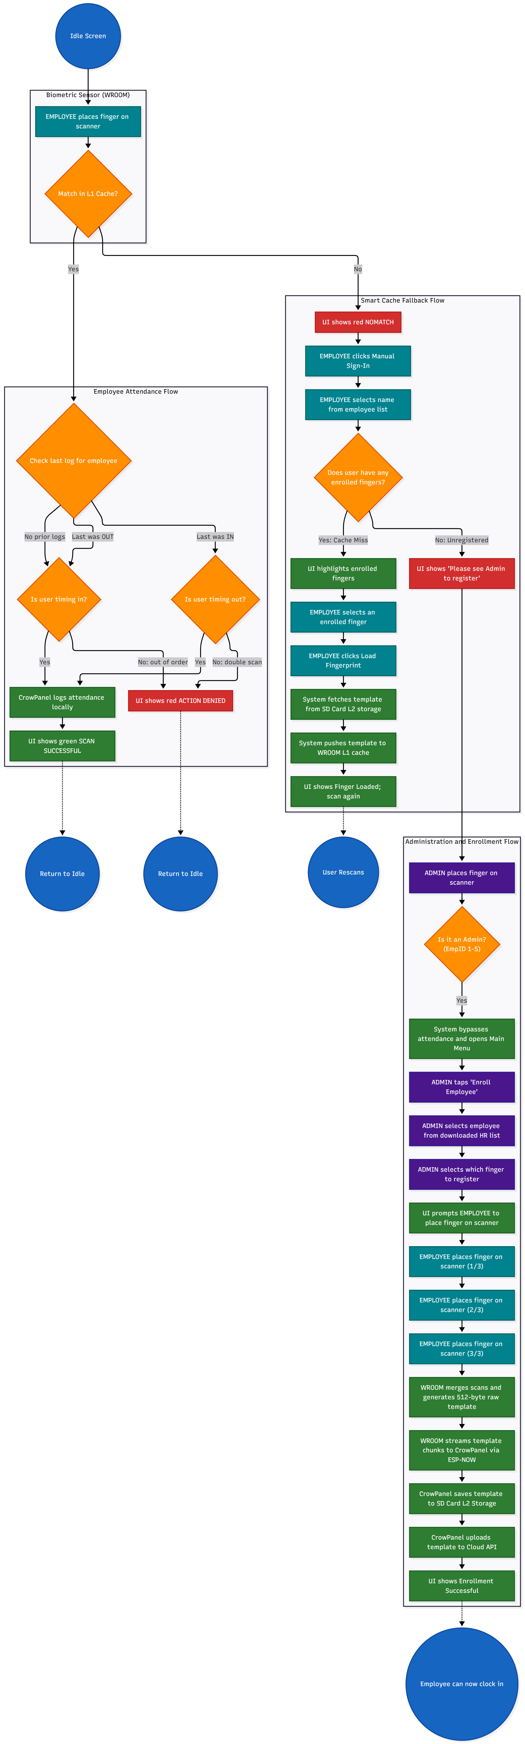
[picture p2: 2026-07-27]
docs/ATTENDANCE_FLOW.png

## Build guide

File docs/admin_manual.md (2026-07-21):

# Biometrics Manpro System - Administrator Manual

Welcome to the Administrator Manual for the Biometrics Time-In/Time-Out System. This guide provides an overview of the device's user interface, detailing how to navigate through the various screens and manage the device effectively.

---

## 1. Initial Setup Screens

When you power on the device for the first time (or after a factory reset), you will be guided through an initial setup sequence.

### Wi-Fi Setup Screen
*   **Purpose**: Connects the device to your local network.
*   **Usage**: Select your Wi-Fi network from the list of available networks and enter the password. A successful connection is required for cloud syncing and remote management.

### Device Activation Screen
*   **Purpose**: Links the hardware to your company's account.
*   **Usage**: Enter the provided secure activation code/token. Once validated, the device will unlock and load the standard operating interface.

---

## 2. Standard Operation

### Idle / Standby Screen
*   **Purpose**: The default state of the device, designed for everyday employee interaction.
*   **What it shows**: The current time, date, and a prompt indicating that the device is ready to read a fingerprint.
*   **Action**: Employees place their finger on the scanner. The screen will transition to the **Result Screen** upon a scan.
*   **Admin Access**: Administrators can access the Main Menu by tapping a specific area (often a gear icon or a long-press on the screen, depending on your exact configuration) and entering the admin PIN.

### Scan Result Screen
*   **Purpose**: Provides immediate visual feedback to the employee.
*   **Success**: Displays a green/teal confirmation indicating a successful "Time In" or "Time Out", along with the employee's name.
*   **Failure**: Displays a red warning (e.g., "Fingerprint Not Recognized" or "Please Try Again") if the scan fails or the employee is not enrolled.
*   **Timeout**: This screen will automatically return to the Idle Screen after a few seconds.

---

## 3. Administrator Main Menu

The Main Menu is the central hub for all administrative tasks. From here, you can navigate to the three primary management modules: **Enrollment**, **Logs**, and **Settings**.

### Enrollment Screen
*   **Purpose**: Add new employees to the biometric database.
*   **Usage**: 
    1. Enter the Employee ID or Name.
    2. Follow the on-screen prompts instructing the user to place their finger on the scanner multiple times (usually 3 times) to capture a reliable template.
    3. Save the profile. The employee can now use the Idle Screen to clock in/out.

### Attendance Logs
*   **Purpose**: View a localized history of recent time-in and time-out events.
*   **Usage**: Scroll through the list of recent scans to verify attendance or troubleshoot missed punches. (Note: Complete logs are typically synced to the main server dashboard).

---

## 4. Device Settings

The Settings Hub allows you to configure the hardware and system preferences.

### Display Settings
*   **Brightness**: Slide to adjust the screen backlight intensity.
*   **Screen Timeout**: Set how long the screen stays awake before dimming or turning off to save power (e.g., 30 seconds, 1 minute, or Never).

### Clock & Date Settings
*   **Purpose**: Ensure the time logs are accurate.
*   **Usage**: You can manually set the time and date, or ensure the device is successfully pulling the time via NTP (Network Time Protocol) over Wi-Fi.

### Server Configuration
*   **Purpose**: Manage backend connectivity.
*   **Usage**: Configure API endpoints, sync intervals, or update the target server where attendance data is sent. *Only modify these if instructed by IT support.*

### Danger Zone / Reset
*   **Purpose**: Destructive actions that cannot be undone.
*   **Usage**: 
    *   **Clear All Data**: Erases all enrolled fingerprints and local logs.
    *   **Factory Reset**: Wipes all Wi-Fi settings, activation tokens, and employee data, returning the device to its out-of-the-box state. 
    *   *A warning prompt will ask for confirmation before executing these actions.*

---

*For further technical support or issues not covered in this manual, please contact your system provider.*

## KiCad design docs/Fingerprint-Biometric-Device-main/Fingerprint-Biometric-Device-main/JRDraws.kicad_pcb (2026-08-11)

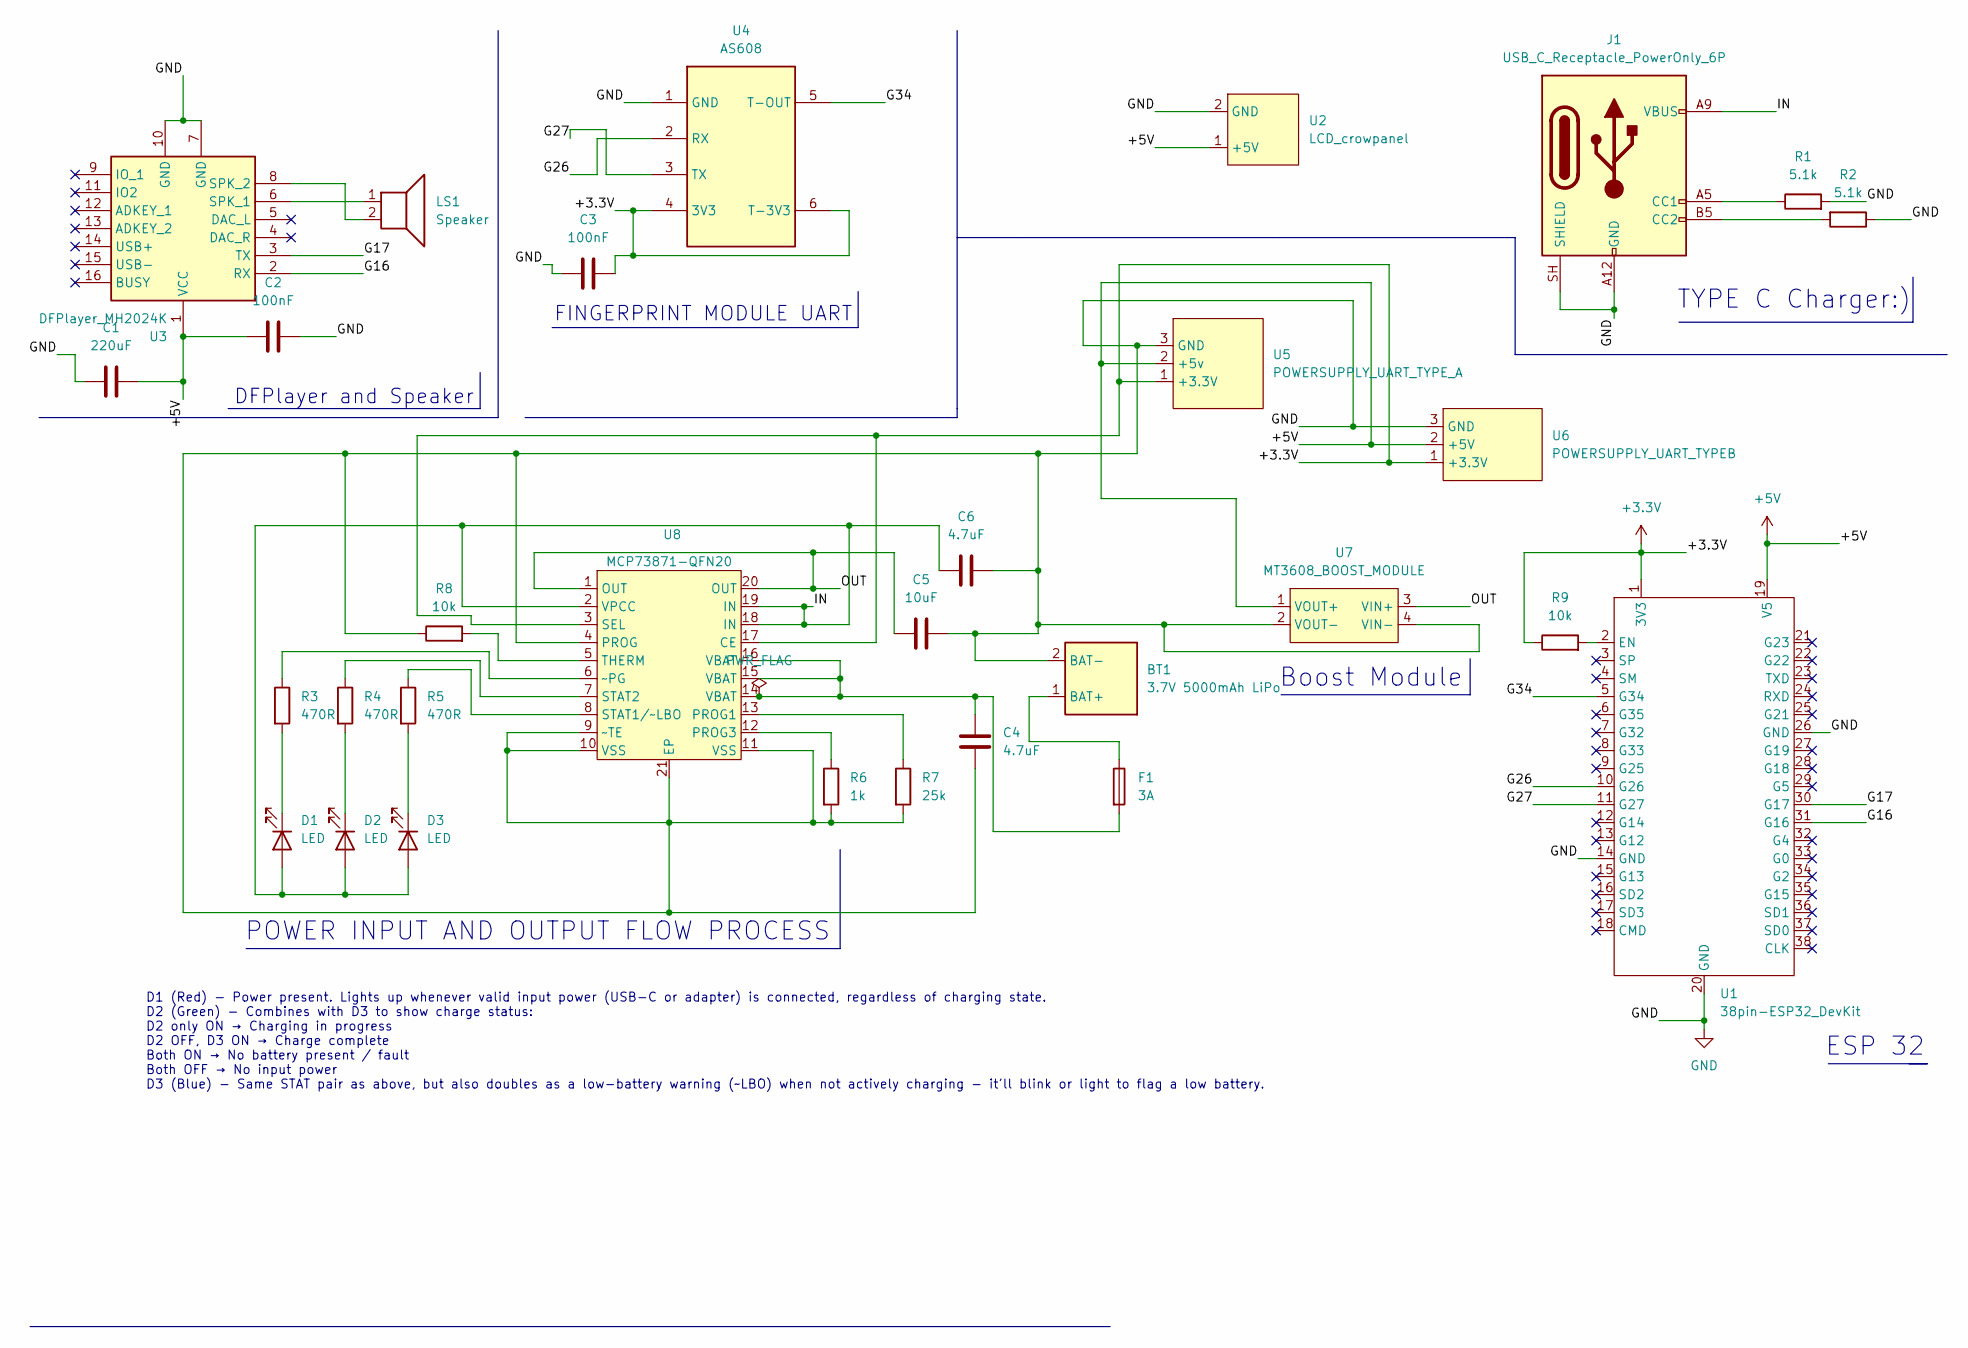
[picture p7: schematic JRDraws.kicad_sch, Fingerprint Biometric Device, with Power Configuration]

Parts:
BT1: 3.7V 5000mAh LiPo; JST_PH_S2B-PH-K_1x02_P2.00mm_Horizontal
C1: 220uF; CP_Radial_D8.0mm_P3.50mm
C2, C3: 100nF; C_Disc_D5.0mm_W2.5mm_P5.00mm
C4, C6: 4.7uF; CP_Radial_D5.0mm_P2.00mm
C5: 10uF; CP_Radial_D5.0mm_P2.00mm
D1, D2, D3: LED; LED_D5.0mm
F1: 3A; Fuse_Bourns_MF-RG300
J1: USB_C_Receptacle_PowerOnly_6P; USB_C_Receptacle_GCT_USB4125-xx-x_6P_TopMnt_Horizontal
LS1: Speaker; JST_PH_S2B-PH-K_1x02_P2.00mm_Horizontal
R1, R2: 5.1k; R_Axial_DIN0207_L6.3mm_D2.5mm_P10.16mm_Horizontal
R3, R4, R5: 470R; R_Axial_DIN0207_L6.3mm_D2.5mm_P10.16mm_Horizontal
R6: 1k; R_Axial_DIN0207_L6.3mm_D2.5mm_P10.16mm_Horizontal
R7: 25k; R_Axial_DIN0207_L6.3mm_D2.5mm_P10.16mm_Horizontal
R8, R9: 10k; R_Axial_DIN0207_L6.3mm_D2.5mm_P10.16mm_Horizontal
U1: 38pin-ESP32_DevKit; ESP32
U2: LCD_crowpanel; JST_PH_S2B-PH-K_1x02_P2.00mm_Horizontal
U3: DFPlayer_MH2024K; DFPPLAYER
U4: AS608; JST_PH_S6B-PH-K_1x06_P2.00mm_Horizontal
U5: POWERSUPPLY_UART_TYPE_A; JST_XH_S3B-XH-A_1x03_P2.50mm_Horizontal
U6: POWERSUPPLY_UART_TYPEB; JST_XH_S3B-XH-A_1x03_P2.50mm_Horizontal
U7: MT3608_BOOST_MODULE
U8: MCP73871-QFN20; QFN-20-1EP_4x4mm_P0.5mm_EP2.6x2.6mm

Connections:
+3.3V: C3.2, R9.1, U1.1 (3V3), U4.4 (3V3), U4.6 (T-3V3), U5.1 (+3.3V), U6.1 (+3.3V), U8.3 (SEL), U8.17 (CE)
+5V: C1.1, C2.1, U1.19 (V5), U2.1 (+5V), U3.1 (VCC), U5.2 (+5v), U6.2 (+5V), U7.1 (VOUT+)
/G16: U1.31 (G16), U3.2 (RX)
/G17: U1.30 (G17), U3.3 (TX)
/G26: U1.10 (G26), U4.2 (RX)
/G27: U1.11 (G27), U4.3 (TX)
/G34: U1.5 (G34), U4.5 (T-OUT)
/IN: C6.2, D1.2 (A), D2.2 (A), D3.2 (A), J1.A9 (VBUS), J1.B9 (VBUS), U8.2 (VPCC), U8.18 (IN), U8.19 (IN)
/OUT: C5.2, U7.3 (VIN+), U8.1 (OUT), U8.20 (OUT)
GND: BT1.2 (BAT-), C1.2, C2.2, C3.1, C4.2, C5.1, C6.1, J1.A12 (GND), J1.B12 (GND), J1.SH (SHIELD), R1.2, R2.1, R6.2, R7.2, R8.1, U1.14 (GND), U1.20 (GND), U1.26 (GND), U2.2 (GND), U3.7 (GND), U3.10 (GND), U4.1 (GND), U5.3 (GND), U6.3 (GND), U7.2 (VOUT-), U7.4 (VIN-), U8.4 (PROG), U8.9 (~TE), U8.10 (VSS), U8.11 (VSS), U8.21 (EP)
unnamed: BT1.1 (BAT+), F1.1
unnamed: C4.1, F1.2, U8.14 (VBAT), U8.15 (VBAT), U8.16 (VBAT)
unnamed: D1.1 (K), R3.2
unnamed: D2.1 (K), R4.2
unnamed: D3.1 (K), R5.2
unnamed: J1.A5 (CC1), R1.1
unnamed: J1.B5 (CC2), R2.2
unnamed: R9.2, U1.2 (EN)
unnamed: LS1.1, U3.6 (SPK_1)
unnamed: LS1.2, U3.8 (SPK_2)
unnamed: R7.1, U8.13 (PROG1)
unnamed: R6.1, U8.12 (PROG3)
unnamed: R5.1, U8.8 (STAT1/~LBO)
unnamed: R4.1, U8.7 (STAT2)
unnamed: R8.2, U8.5 (THERM)
unnamed: R3.1, U8.6 (~PG)

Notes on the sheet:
ESP 32
FINGERPRINT MODULE UART
TYPE C Charger:)
Boost Module
D1 (Red) - Power present. Lights up whenever valid input power (USB-C or adapter) is connected, regardless of charging state. D2 (Green) - Combines with D3 to show charge status: D2 only ON → Charging in progress D2 OFF, D3 ON → Charge complete Both ON → No battery present / fault Both OFF → No inp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
POWER INPUT AND OUTPUT FLOW PROCESS
DFPlayer and Speaker

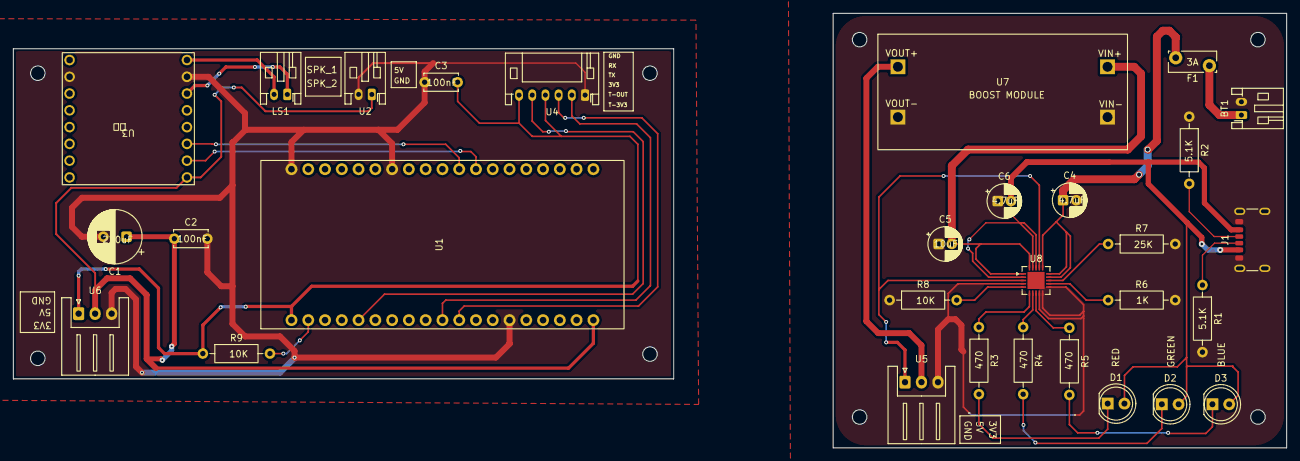
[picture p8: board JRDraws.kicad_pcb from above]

Board: 2 copper layers, 192.8 x 65.8 mm, 30 parts (0 on the bottom side), 26 nets.

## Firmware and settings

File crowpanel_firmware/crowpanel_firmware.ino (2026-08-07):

/**
 * crowpanel_firmware.ino
 * Biometrics Employee Time-In/Time-Out System - Display Node
 *
 * Board   : ESP32-S3 CrowPanel 5.0" (800x480)
 * Comms   : ESP-NOW wireless link to WROOM (no UART wire)
 *
 * Libraries (install via Arduino Library Manager):
 *   - LVGL 8.x/9.x
 *   - ArduinoJson
 *   - Arduino_GFX_Library
 */

#include <Arduino.h>
#include "src/core/display_driver.h"
#include <lvgl.h>
#include <esp_system.h>

#include "src/core/data_manager.h"
#include "src/core/comm_manager.h"
#include "src/ui/ui_manager.h"
#include "src/splash/manpro_splash.h"


// Display configuration
LGFX lcd;
unsigned long last_flush_time = 0; // Tracks the last time LVGL pushed a frame


// Screen blanking state
bool screen_is_awake = true;
unsigned long last_touch_time = 0;
static bool wait_for_release = false;

void manpro_wake_display() {
  if (!screen_is_awake) {
    screen_is_awake = true;
    lcd.setBrightness(DataManager::getBrightness());
  }
  last_touch_time = millis();
}

#ifndef LV_CONF_INCLUDE_SIMPLE
  #define LV_CONF_INCLUDE_SIMPLE
#endif

// Partial render buffer — 240 lines per buf in PSRAM. Blocking ops are off the main thread.
static const uint16_t LV_BUF_LINES = 240;

#if LVGL_VERSION_MAJOR >= 9
static void *buf1;
static void *buf2;
static lv_display_t *disp;
static lv_indev_t   *indev;

void my_disp_flush(lv_display_t *disp, const lv_area_t *area, uint8_t *px_map) {
  uint32_t w = (area->x2 - area->x1 + 1);
  uint32_t h = (area->y2 - area->y1 + 1);
  lcd.startWrite();
  lcd.pushImage(area->x1, area->y1, w, h, (lgfx::rgb565_t *)px_map);
  lcd.endWrite();
  lcd.waitDisplay();
  last_flush_time = millis(); // Record exact time render finished
  lv_display_flush_ready(disp);
}

void my_touch_read(lv_indev_t *indev, lv_indev_data_t *data) {
  uint16_t touchX, touchY;
  bool touched = lcd.getTouch(&touchX, &touchY);
  if (touched) {
    if (!screen_is_awake) {
      manpro_wake_display();
      wait_for_release = true;
    }
    
    if (wait_for_release) {
      data->state = LV_INDEV_STATE_RELEASED;
      return;
    }
    
    last_touch_time = millis();
    data->state   = LV_INDEV_STATE_PRESSED;
    data->point.x = touchX;
    data->point.y = touchY;
  } else {
    wait_for_release = false;
    data->state = LV_INDEV_STATE_RELEASED;
  }
}
#else
static lv_disp_draw_buf_t draw_buf;
static lv_color_t        *buf1;
static lv_color_t        *buf2;
static lv_disp_drv_t      disp_drv;
static lv_indev_drv_t     indev_drv;

void my_disp_flush(lv_disp_drv_t *disp, const lv_area_t *area, lv_color_t *color_p) {
  uint32_t w = (area->x2 - area->x1 + 1);
  uint32_t h = (area->y2 - area->y1 + 1);
  lcd.startWrite();
  lcd.pushImage(area->x1, area->y1, w, h, (lgfx::rgb565_t *)&color_p->full);
  lcd.endWrite();
  lcd.waitDisplay();
  lv_disp_flush_ready(disp);
}

void my_touch_read(lv_indev_drv_t *indev_drv, lv_indev_data_t *data) {
  uint16_t touchX, touchY;
  bool touched = lcd.getTouch(&touchX, &touchY);
  if (touched) {
    if (!screen_is_awake) {
      manpro_wake_display();
      wait_for_release = true;
    }
    
    if (wait_for_release) {
      data->state = LV_INDEV_STATE_REL;
      return;
    }
    
    last_touch_time = millis();
    data->state   = LV_INDEV_STATE_PR;
    data->point.x = touchX;
    data->point.y = touchY;
  } else {
    wait_for_release = false;
    data->state = LV_INDEV_STATE_REL;
  }
}
#endif

SemaphoreHandle_t g_lvglMutex = NULL;

// Initialization
void setup() {
  Serial.begin(115200);
  Serial.printf("[BOOT] Reset reason: %d\n", esp_reset_reason());

  delay(500);
  if (Serial && Serial.availableForWrite() > 32) {
    Serial.println("\n=== Biometrics CrowPanel Display ===");
  }

  // Initialize filesystem and data
  DataManager::begin();
  
  

  // Check PSRAM availability
  size_t psram_free = heap_caps_get_free_size(MALLOC_CAP_SPIRAM);
  if (Serial && Serial.availableForWrite() > 64) {
    Serial.printf("[PSRAM] Free SPIRAM: %u bytes\n", psram_free);
    if (psram_free < 800000) Serial.println("[PSRAM] SPIRAM unavailable or low");
  }

  // Initialize communications before LCD to avoid hardware conflicts
  CommManager::begin();

  // Reset backlight
  pinMode(2, OUTPUT);
  digitalWrite(2, LOW);
  delay(200);

  // Initialize display
  lcd.init();
  lcd.setRotation(0);
  lcd.fillScreen(TFT_BLACK);

  // LVGL
  lv_init();
  
  // Partial render double buffer: 800x240 lines, allocated in PSRAM.
#if LVGL_VERSION_MAJOR >= 9
  uint32_t buf_sz = LCD_WIDTH * LV_BUF_LINES * 2; // 2 bytes per pixel (RGB565)
  buf1 = heap_caps_malloc(buf_sz, MALLOC_CAP_SPIRAM | MALLOC_CAP_8BIT);
  buf2 = heap_caps_malloc(buf_sz, MALLOC_CAP_SPIRAM | MALLOC_CAP_8BIT);
  if (!buf1 || !buf2) {
    Serial.println("[LVGL] FATAL: Could not allocate PSRAM buffers!");
  }

  disp = lv_display_create(LCD_WIDTH, LCD_HEIGHT);
  lv_display_set_flush_cb(disp, my_disp_flush);
  lv_display_set_buffers(disp, buf1, buf2, buf_sz, LV_DISPLAY_RENDER_MODE_PARTIAL);

  indev = lv_indev_create();
  lv_indev_set_type(indev, LV_INDEV_TYPE_POINTER);
  lv_indev_set_read_cb(indev, my_touch_read);
#else
  // Partial render double buffer: 800*240 pixels at sizeof(lv_color_t) each, in PSRAM.
  buf1 = (lv_color_t *)heap_caps_malloc(LCD_WIDTH * LV_BUF_LINES * sizeof(lv_color_t), MALLOC_CAP_SPIRAM | MALLOC_CAP_8BIT);
  buf2 = (lv_color_t *)heap_caps_malloc(LCD_WIDTH * LV_BUF_LINES * sizeof(lv_color_t), MALLOC_CAP_SPIRAM | MALLOC_CAP_8BIT);
  if (!buf1 || !buf2) {
    Serial.println("[LVGL] FATAL: Could not allocate PSRAM buffers!");
    free(buf1); free(buf2);
    buf1 = (lv_color_t *)heap_caps_malloc(LCD_WIDTH * 40 * sizeof(lv_color_t), MALLOC_CAP_INTERNAL | MALLOC_CAP_8BIT);
    buf2 = NULL;
  }

  lv_disp_draw_buf_init(&draw_buf, buf1, buf2, buf1 && buf2 ? LCD_WIDTH * LV_BUF_LINES : LCD_WIDTH * 40);

  lv_disp_drv_init(&disp_drv);
  disp_drv.hor_res  = LCD_WIDTH;
  disp_drv.ver_res  = LCD_HEIGHT;
  disp_drv.flush_cb = my_disp_flush;
  disp_drv.draw_buf = &draw_buf;
  lv_disp_t * my_disp = lv_disp_drv_register(&disp_drv);
  // Guard for LVGL 8.x
  if (my_disp && my_disp->refr_timer) {
    lv_timer_set_period(my_disp->refr_timer, 10);
  }

  lv_indev_drv_init(&indev_drv);
  indev_drv.type    = LV_INDEV_TYPE_POINTER;
  indev_drv.read_cb = my_touch_read;
  lv_indev_drv_register(&indev_drv);
#endif

  // CommManager initialized earlier

  // Show boot splash screen
  manpro_show_splash(UIManager::loadInitialScreen);

  // Draw first splash frame immediately
  lv_timer_handler();

  // Apply user-configured brightness
  lcd.setBrightness(DataManager::getBrightness());
  last_touch_time = millis(); // Initialize inactivity timer

  // Build UI screens in background
  UIManager::begin();
  
  if (g_lvglMutex == NULL) {
      g_lvglMutex = xSemaphoreCreateRecursiveMutex();
  }
}

// Main Loop
unsigned long lastLvglTick = 0;

void loop() {
  unsigned long now = millis();
  if (now != lastLvglTick) {
    lv_tick_inc(now - lastLvglTick);
    lastLvglTick = now;
  }
  
  if (g_lvglMutex) xSemaphoreTakeRecursive(g_lvglMutex, portMAX_DELAY);
  lv_task_handler();
  if (g_lvglMutex) xSemaphoreGiveRecursive(g_lvglMutex);

  CommManager::process();

  int timeout_sec = DataManager::getScreenTimeout();
  if (timeout_sec > 0 && screen_is_awake && millis() - last_touch_time > (unsigned long)timeout_sec * 1000) {
    screen_is_awake = false;
    lcd.setBrightness(0);
  }

  yield();
}

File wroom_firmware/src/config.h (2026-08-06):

#pragma once

// ── Development / Testing ─────────────────────────────────────────────────────
// Uncomment to simulate fingerprint scans and bypass the physical AS608 hardware.
// #define MOCK_SENSOR 1  // Uncomment ONLY for hardware-less dev testing

// ── Fingerprint Sensor (AS608) ────────────────────────────────────────────────
#define PIN_FP_RX    27   // AS608 TX  → WROOM UART1 RX
#define PIN_FP_TX    26   // AS608 RX  ← WROOM UART1 TX
#define PIN_FP_TOUCH 34   // AS608 T-OUT: pulled HIGH when a finger is present
#define MAX_SLOTS    127  // Maximum AS608 template slots (sensor-rated capacity)

// ── Audio (DFPlayer Mini & Buzzer) ────────────────────────────────────────────
#define PIN_DFP_RX   17   // DFPlayer TX → WROOM UART2 RX
#define PIN_DFP_TX   16   // DFPlayer RX ← WROOM UART2 TX
#define PIN_BUZZER   13   // Active Buzzer GPIO

// MP3 Folder Track Numbers
#define TRACK_TIME_IN         1
#define TRACK_TIME_OUT        2
#define TRACK_NOT_RECOGNIZED  3
#define TRACK_ALREADY_LOGGED  4
#define TRACK_ENROLLED        5
#define TRACK_ENROLL_FAILED   6
// TRACK_RESET_CONFIRM 7 is skipped as per user request (buzzer instead)

#define PIN_FACTORY_RESET 14

// ── Device Identity ───────────────────────────────────────────────────────────
// Sent to the backend to identify and verify this unit's registration.
// Must match DEVICE_ID_HARDCODED in the CrowPanel firmware.
#define DEVICE_ID    "F001-2608-6AEC-ON92"

// Backend API base URL.
// Change to your server's LAN IP (e.g. http://192.168.1.50:8000) for local dev.
#define API_BASE_URL "https://demo.manpromanagement.com"

// ── ESP-NOW ───────────────────────────────────────────────────────────────────
// The router must be locked to a fixed channel (e.g. 1).
// Both WROOM and CrowPanel must use the same value.
#define ESPNOW_CHANNEL     1
#define ESPNOW_PAYLOAD_MAX 251

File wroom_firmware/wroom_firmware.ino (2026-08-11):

/**
 * wroom_firmware.ino
 * Biometrics Employee Time-In/Time-Out System — Controller Node

 *
 * Board     : ESP32-WROOM-32
 * AS608     : UART1  RX=GPIO27, TX=GPIO26, TOUCH=GPIO34
 * DS3231    : I2C    SDA=GPIO21, SCL=GPIO22
 * CrowPanel : ESP-NOW wireless link (no UART wire)
 *
 * Libraries (install via Arduino Library Manager):
 *   - Adafruit Fingerprint Sensor Library  (Adafruit)
 *   - RTClib                               (Adafruit)
 *   - ArduinoJson                          (Benoit Blanchon)
 *   - DFRobotDFPlayerMini                  (DFRobot)
 *
 * Hardware Wiring (Audio):
 *   - DFPlayer TX   -> WROOM GPIO17 (RX2)
 *   - DFPlayer RX   -> WROOM GPIO16 (TX2)
 *   - DFPlayer VCC  -> 5V or 3.3V (depends on module/power)
 *   - DFPlayer GND  -> GND
 *   - DFPlayer SPK+ -> Speaker +
 *   - DFPlayer SPK- -> Speaker -
 *   - Buzzer +      -> WROOM GPIO13
 *   - Buzzer GND    -> GND
 *
 * Source layout:
 *   src/config.h                   pin definitions, device ID, ESP-NOW constants
 *   src/employee_db.h/.cpp         employee records and slot lookup
 *   src/comms.h/.cpp               ESP-NOW transport (send, ring buffer, channel sync)
 *   src/wifi_manager.h/.cpp        WiFi connection, scan, auto-reconnect
 *   src/time_manager.h/.cpp        RTC, NTP sync, timestamp formatter
 *   src/fingerprint_manager.h/.cpp AS608 sensor, match, enroll
 *   src/activation.h/.cpp          backend API call for device registration
 *   src/command_handler.h/.cpp     command dispatcher, factory reset, fingerprint poll
 *
 * USB Serial commands (connect at 115200 baud):
 *   ENROLL:<emp_id>:<finger_index>   enroll a finger  (e.g. ENROLL:1:0)
 *   DELETE:<emp_id>:<finger_index>   erase a template  (e.g. DELETE:1:0)
 *   RESET                            reboot this board
 *   GHOST_LOGIN / NUKE_USERS / DEBUG_COMMS   dev backdoors (forwarded to CrowPanel)
 */

#include <esp_system.h>
#include "src/config.h"
#include "src/employee_db.h"
#include "src/comms.h"
#include "src/wifi_manager.h"
#include "src/time_manager.h"
#include "src/fingerprint_manager.h"
#include "src/activation.h"
#include "src/command_handler.h"
#include "src/sync_manager.h"
#include "src/audio_manager.h"

// Initialization

void setup() {
  Serial.begin(115200);
  delay(500);
  Serial.printf("[BOOT] Reset reason: %d\n", esp_reset_reason());
  Serial.println("\n=== Biometrics WROOM Controller ===");

  employeeDbInit();          // Load employee database
  wifiManagerInit();         // Initialize WiFi
  fingerprintManagerInit();  // Initialize fingerprint sensor
  espNowInit();              // Initialize ESP-NOW
  timeManagerInit();         // Initialize RTC
  SyncManager::init();       // Initialize binary sync manager
  audioManagerInit();        // Initialize DFPlayer and Buzzer

  pinMode(PIN_FACTORY_RESET, INPUT_PULLDOWN);

  Serial.println("\nReady. Serial commands:");
  Serial.println("  ENROLL:<emp_id>:<finger_index>   e.g. ENROLL:1:0");
  Serial.println("  DELETE:<emp_id>:<finger_index>   e.g. DELETE:1:0");
  Serial.println("  RESET");

  // Notify CrowPanel of boot to sync state
  send("{\"type\":\"WROOM_BOOT\"}");
}

// Main Loop

static unsigned long lastTimeBcast = 0;

void loop() {
  handleFactoryResetButton();

  // Broadcast time to CrowPanel every second
  if (millis() - lastTimeBcast >= 1000) {
    lastTimeBcast = millis();
    sendQuiet("{\"type\":\"TIME\",\"ts\":\"" + getTimestamp() + "\"}");
  }

  wifiProcess();  // Handle WiFi background tasks
  ntpProcess();   // Check NTP sync status
  SyncManager::loop(); // Drive background sync machine

  // Dispatch buffered binary sync packets (queued from the RX callback)
  // Must be called BEFORE fingerprintPoll() so ACKs go out promptly.
  syncQueueProcess();

  // Handle Serial commands
  if (Serial.available()) {
    handleCmd(Serial.readStringUntil('\n'));
  }

  // Process incoming ESP-NOW messages
  while (!cpQueueEmpty()) {
    String msg = cpQueuePop();
    if (msg.length() > 0) {
      if (msg.indexOf("\"PING\"") == -1 && msg.indexOf("\"PONG\"") == -1)
        Serial.println("[<-CP] " + msg);
      handleCmd(msg);
    }
  }

  fingerprintPoll();  // Scan for fingerprints
}

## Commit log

2026-07-10 feat: implement UI activation flow for device registration with hardware code display and validation inputs
2026-07-10 feat: add battery icon asset and implementation for enrollment screen
2026-07-11 feat: implement UI manager and settings screen for device configuration
2026-07-11 feat: implement modular UI structure and communication bridge for ESP32-S3 CrowPanel firmware. Fixed pong
    [comm_manager.cpp, ui_settings_clock.cpp]
2026-07-11 feat: implement CrowPanel display driver and firmware base with USB serial non-blocking fix
    [crowpanel_firmware.ino, ui_settings_clock.cpp]
2026-07-12 bug-fix: fixed the 2 device communication
    [comm_manager.cpp, crowpanel_firmware.ino, ui_settings_clock.cpp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]
2026-07-15 added gear icon and main menu now requires admin auth FP
2026-07-15 feat: implement initial firmware structure for ESP32-WROOM controller and CrowPanel UI interface
2026-07-15 feat: initialize WROOM firmware and CrowPanel communication manager with ESP-NOW wireless protocol
2026-07-16 tell crowpanel that the wroom is booted to send the activated status of device
2026-07-16 fixed wifi and channel dropping problem
    [comm_manager.cpp, ui_settings_clock.cpp, wroom_firmware.ino]
2026-07-16 feat: implement data management system and device settings UI for CrowPanel firmware
2026-07-17 fixed the employee screen freezing and tapping the employee freezing
    [comm_manager.cpp, wroom_firmware.ino]
2026-07-17 fingerprint now works and employee registration
2026-07-17 screen freezing are fixed in employee screens and fingerprint finger choosing screen
    [comm_manager.cpp, wroom_firmware.ino]
2026-07-17 working fingerprint UI flow
2026-07-17 feat: implement data manager backend and fingerprint enrollment UI for employee management
2026-07-17 fixed wifi connectivity issues, patched ESP_NOW pain points, fixed some minor bugs and updated some icons
    [comm_manager.cpp]
2026-07-17 added global toast notif and fixed wifi connectivity issues and fingerprint sensor delay
    [comm_manager.cpp, wroom_firmware.ino]
2026-07-18 refactor: reorganize assets with consistent icon_ naming and restructure crowpanel_firmware into src/ subdirectories with updated includes and build fix
    [comm_manager.cpp, crowpanel_firmware.ino]
2026-07-18 Overhaul the Settings Hub into a responsive 3x2 grid, implement hardware display brightness controls, secure the activation token field, and add cross-device API connection testing.
2026-07-20 feat(biometrics): sync db, add UI fp deletion, and fix ESP-NOW timeouts
    - Sync WROOM employee DB with CrowPanel to fix name mismatches
    - Add UI Delete Fingerprint button and Overwrite mode with confirmation modal
    - Preserve Admin slots (1-5) during WIPE_ALL and factory resets
    - Add ESP-NOW PING heartbeats during enrollment to prevent channel hopping drops
    - Fix CrowPanel white-screen flash on factory reset
    [comm_manager.cpp, command_handler.cpp, crowpanel_firmware.ino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]
2026-07-20 feat: implement backend API integration for device activation, employee synchronization, and UI modules for enrollment and settings
2026-07-21 feat: robust employee sync, fp template extraction, and API upload
    **WROOM Firmware:**
    - Implement `getTemplateBytes()` to extract raw binary templates from the AS608 sensor's char buffer.
    - Add `uploadEnrollment()` to Base64-encode and HTTP POST the fingerprint template and metadata to the backend endpoint.
    - Wire template extraction and upload into the `ENROLL:` command handler on success.
    - Add `static_assert` in `sync_protocol.h` to permanently guarantee `SyncDataPacket` + payload never breaches the 250-byte ESP-NOW limit.
    **CrowPanel Firmware:**
    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
2026-07-21 deleted a buggy line of code
    [crowpanel_firmware.ino]
2026-07-21 added label on filter dropdowns and fixed wifi input field bug
2026-07-21 fix: fxed cancel command sent via cmd in crowpanel and added manual time input
    [command_handler.cpp, fingerprint_manager.cpp, time_manager.cpp]
2026-07-21 update: added sync button
2026-07-25 refactor: did an overhaul and bug fixes in the sync logic of the system
    [activation.cpp, comm_manager.cpp, command_handler.cpp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]
2026-07-25 refactor: fix the bug in UI result
    [config.h, time_manager.cpp]
2026-07-25 feat(hardware): integrate DFPlayer audio and buzzer feedback with wiring docs and TEST_HW command
    [audio_manager.cpp, command_handler.cpp, config.h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]
2026-07-26 feat: implement smart cache architecture for dynamic fingerprint template loading
2026-07-27 feat: added 4 pin admin login
2026-07-27 fix: patched the wifi connectivity issue
    [comm_manager.cpp, sync_manager.cpp, wifi_manager.cpp]
2026-07-28 fixed some settings, im sleepy, might forget tomm but to remind my morning self: its to check device info page and centralize the theme tokens like color, typography and stuff
    [comm_manager.cpp, command_handler.cpp, fingerprint_manager.cpp]
2026-07-29 REFACTORl FIXED SOME ISSSUES
    [audio_manager.cpp, comm_manager.cpp, command_handler.cpp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]
2026-08-05 perfectly working prototype
2026-08-05 feat: implement fingerprint management, UI navigation, and system command handling logic
2026-08-11 feat: initialize KiCad project and add custom component footprints
    [Dpad-button-controller.kicad_sch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]
